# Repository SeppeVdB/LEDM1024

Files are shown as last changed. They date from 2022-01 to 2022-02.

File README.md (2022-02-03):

# LEDM1024

The LEDM1024 is a 32x32 LED screen made from scratch using an Atmega328p as the processor.

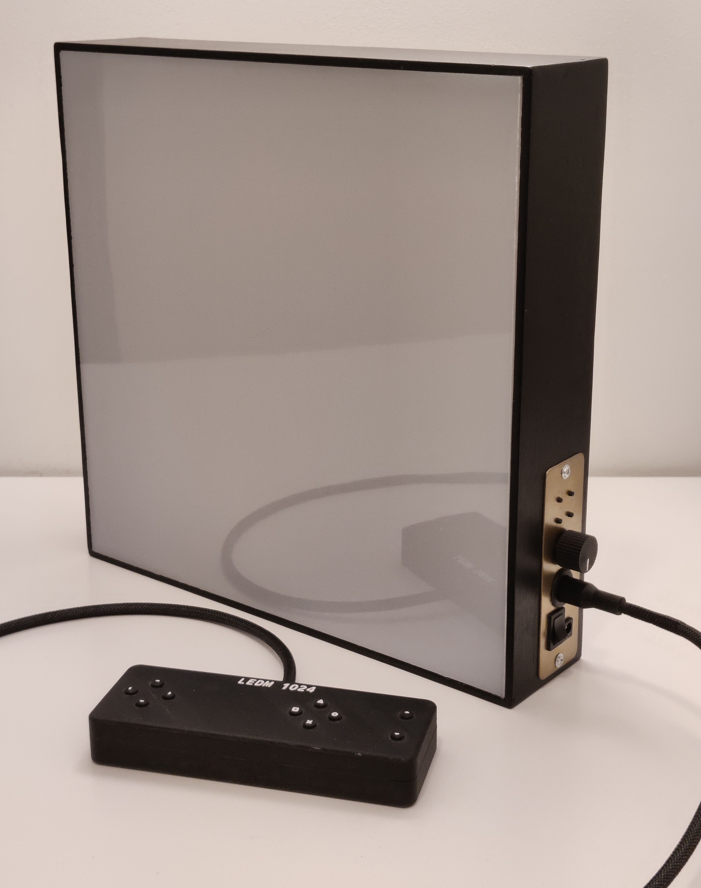
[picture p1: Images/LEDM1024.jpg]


## Applications

The available applications are John Conway's Game of Life, Snake and Pong.

John Conway's Game of Life has a random initial state and evolves until the state becomes stationary or starts oscillating between two states. After this, the app refreshes and a new random initial state is generated. Using the knob on the side panel, the frame rate can be adjusted.

To play Snake, the external controller is needed. The highscore is displayed on the menu screen and updates automatically when this score is exceeded. Normal Snake rules apply, so you lose when you hit the wall or the tail. Each food piece you consume, increases the score by 1. If the frame rate is high enough, the score is increased by 5.

To play Pong, the external controller and two players are needed. One player uses the leftmost up and down buttons and the second player uses the rightmost up and down buttons on the controller. Again, the knob on the side panel can be used to change the frame rate.

## Design

The casing is built around plywood sheet where all the LED's are mounted into. This sheet has a grid of 32x32 holes drilled and all the LED's are gluid in place. The LED leads are soldered to rails of copper wire to connect them in a grid like pattern. In the image below, the LED's are glued in place and the they are connected in rows using relatively thick copper wire to handle the current.

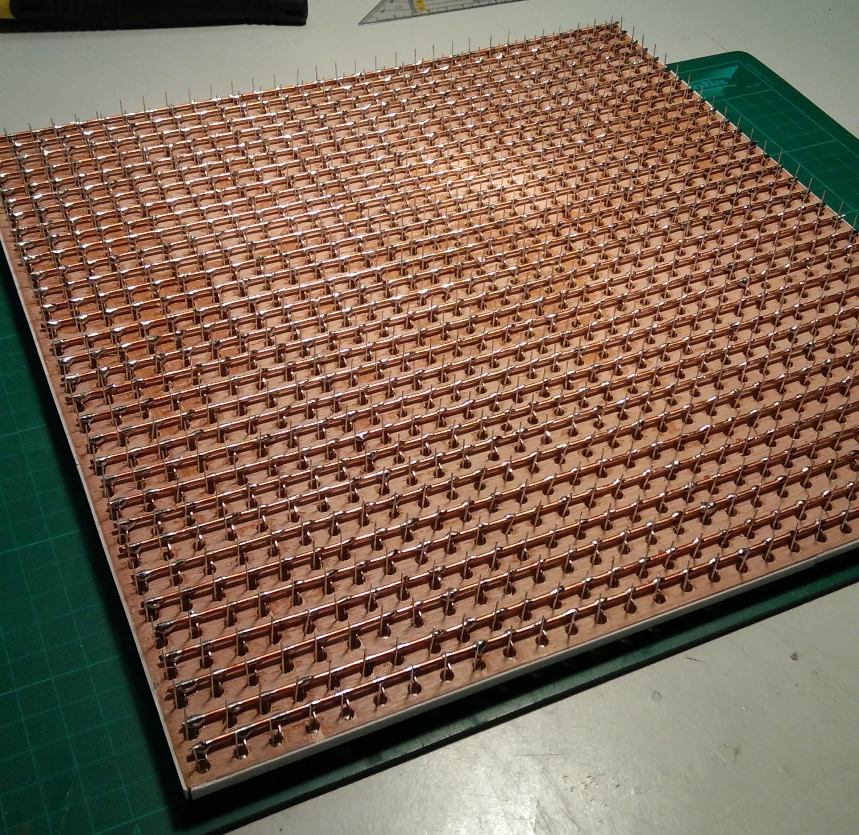
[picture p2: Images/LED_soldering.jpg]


The columns are soldered together using thinner wire and raised above the row connections. Lastly, the rows are connected in pairs to create the 16x64 structure instead of 32x32.

All the circuit boards containing the Atmega328p and shift registers, are mounted on the solder side of this sheet, raised using standoffs (insulated with heat shrink to prevent short circuits of the underlying wires). These circuit boards all receive a power line from the processor board and the signal lines are chained through the shift registers as shown below.

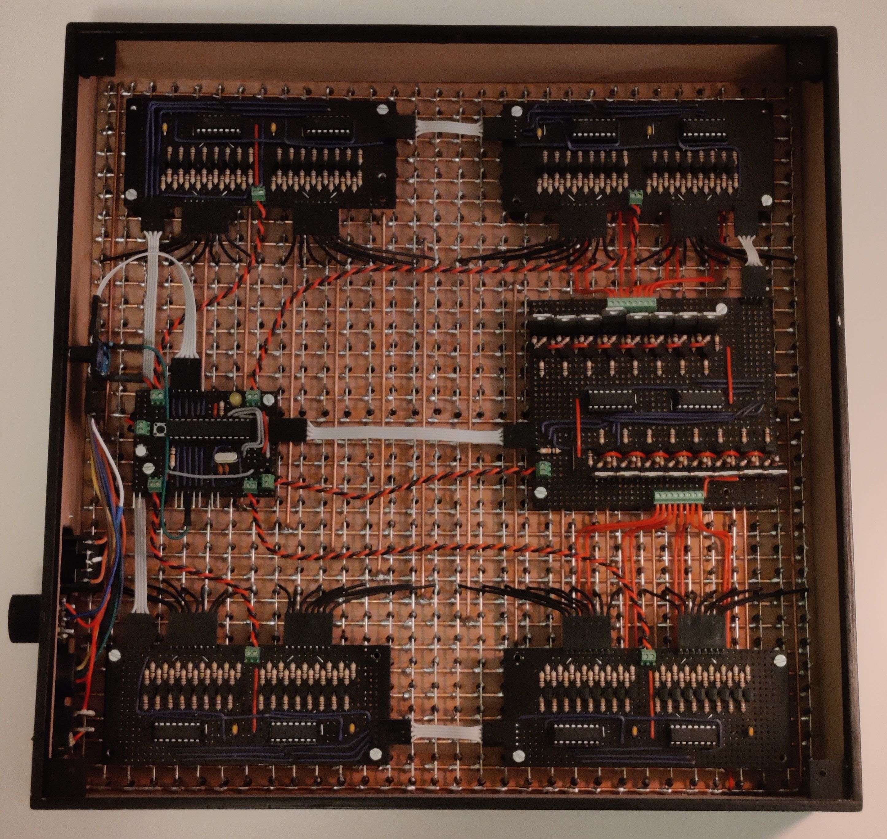
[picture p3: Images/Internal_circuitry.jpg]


The side panels are glued onto the central sheet. The right panel has a hole for the control panel which is made from a sheet of brass. Some 3d printed corner pieces allow for a clear acrylic sheet to be used as back plate. A clear acrylic sheet was chosen such that the internal circuitry is still visible.

To create a grid like pattern on the screen, a grid was 3d printed and inserted between the LED's.

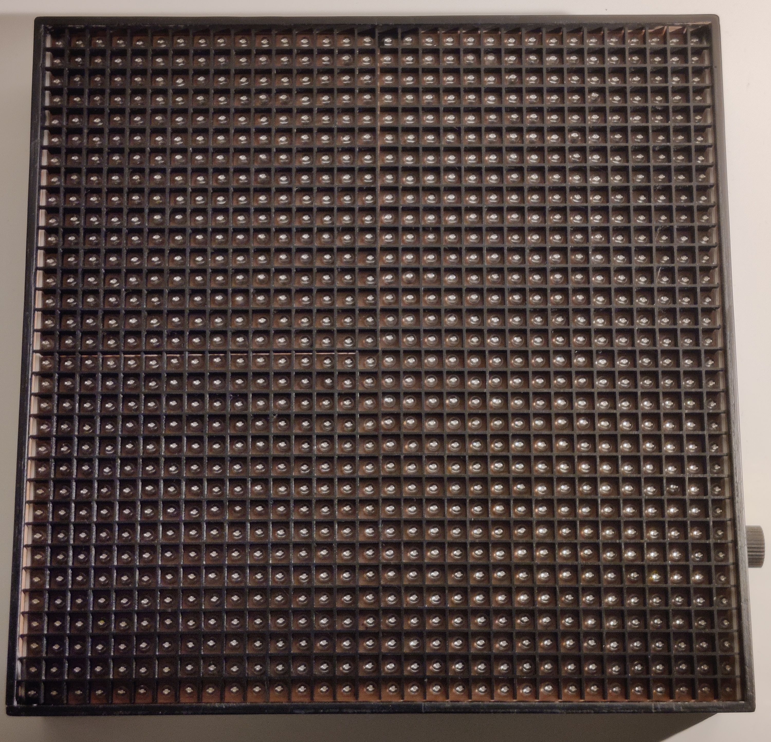
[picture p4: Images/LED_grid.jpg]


A diffusive acrylic plate is used as the front plate to create a pixel look.

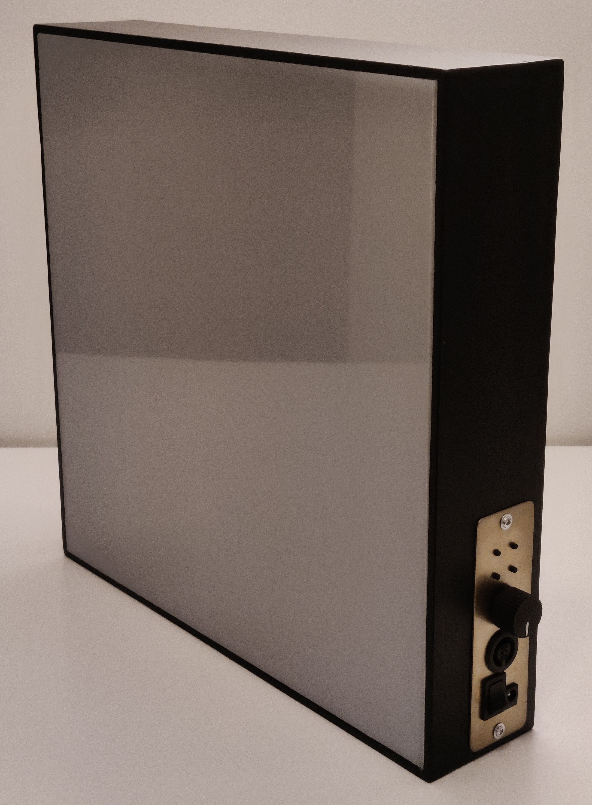
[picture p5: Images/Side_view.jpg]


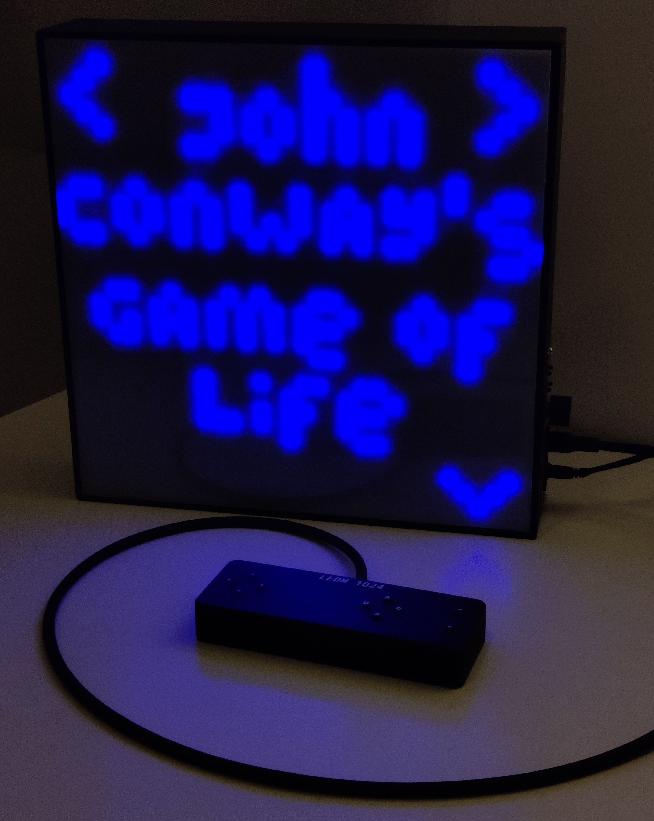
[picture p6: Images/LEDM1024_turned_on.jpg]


I'm sorry for the picture quality, but it is very difficult to capture the screen on camera. In reality the pixels are perfectly square.

## Electronics

### Processor

The processor is an Atmega328p (Arduino Uno chip). To control the 1024 LED's, 10 74HC595 shift registers are used together with multiplexing. Using these shift registers, the Atmega processor can control 80 separate pins using only four pins on the processor itself (clock, data, latch, and enable). The 32x32 LED grid is internally connected as if it where a 16x64 LED grid, resulting in 80 pins needed for multiplexing.

When multiplexing, each row of LED's is turned on separately. This is done at a frequency of about 8kHz to eliminate flickering. Because each row is only turned on 1/16 of the time, the perceived brightness of the LED's is also 1/16 of the normal brightness. This is the reason why the LED's are connected in a 16x64 grid, because a 32x32 grid would result in a brightness level of 1/32, which would be too low. Changing the layout to a 8x128 grid would increase the brightness to 1/8, which is better than 1/16, but this would increase the total amount of current that runs through one row. The operating current of each LED is 20mA, having 64 LED's in one row results in a total current per row of 1.28A. Compared to 2.56A in a 8x128 grid layout, a 16x64 layout was chosen as trade-off between brightness and total current.

### Controller

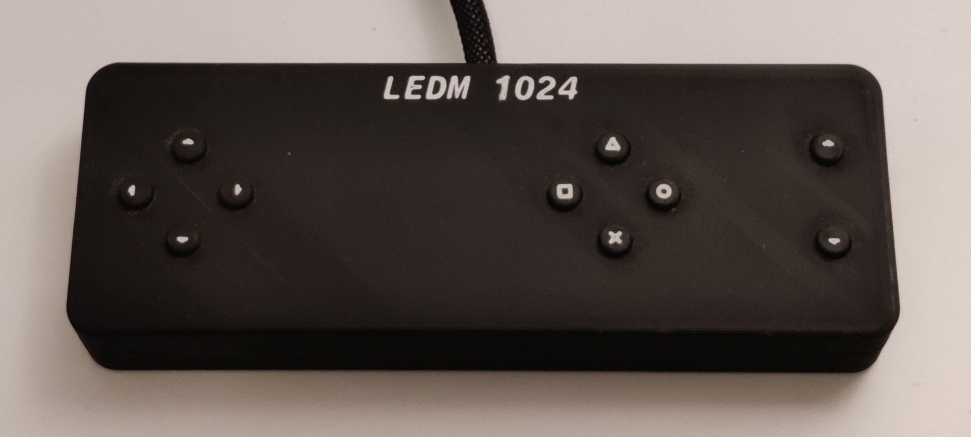
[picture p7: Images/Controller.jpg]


To play Snake and Pong, an external controller is needed to allow for more functionality. The external controller has 10 buttons and the side panel has four plus a rotating knob. Connecting these buttons in the conventional way, 15 pins would have to be used. The cable connecting the external controller would also have to house 12 separate cables (10 for the buttons, one ground, and one signal line to detect if the controller is plugged in). Because this kind of cable is not readily available, button multiplexing was used. Button multiplexing differs from LED multiplexing in that specific valued resistors are used to create an analog voltage signal depending on which buttons are pressed. The image below shows a diagram for multiplexing four buttons.

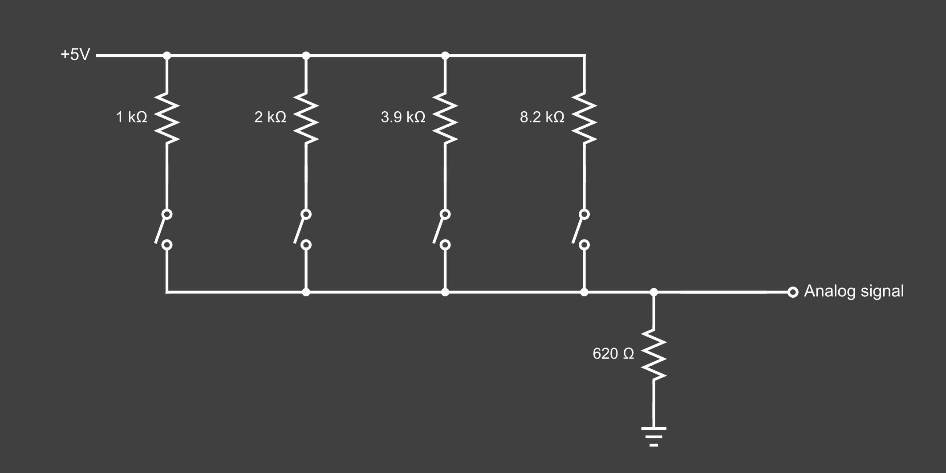
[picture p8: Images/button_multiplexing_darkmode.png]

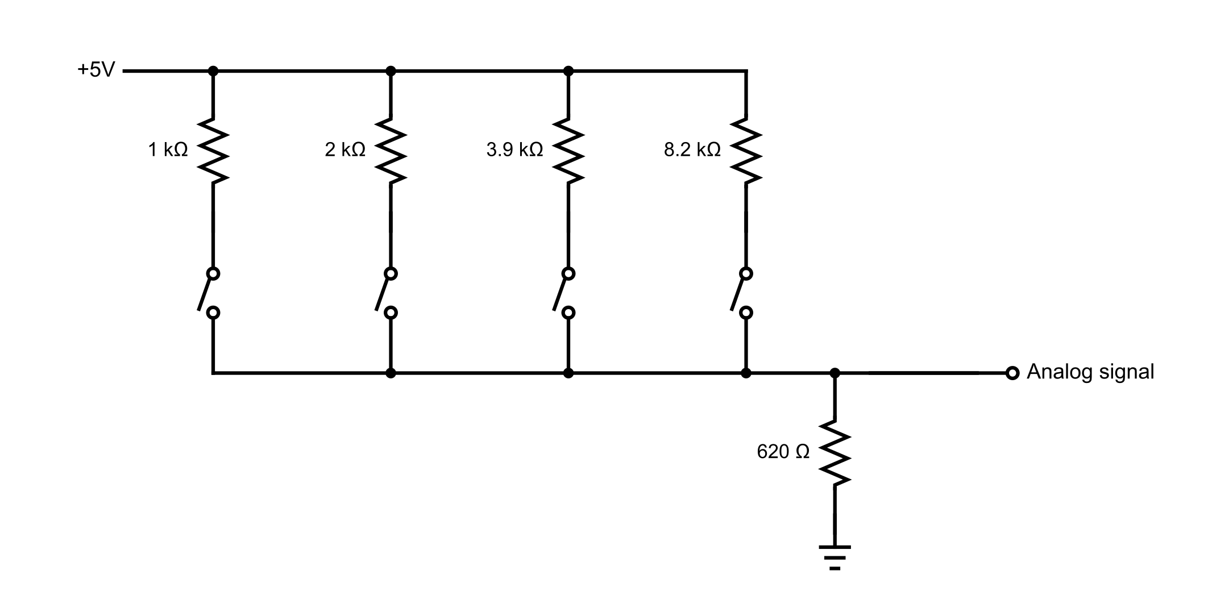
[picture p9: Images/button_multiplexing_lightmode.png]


After a lot of trial and error, these resistor values were chosen to maximise the voltage difference between different button pressed configurations. All the possible values are stored in a look up table. The values are ordered in ascending order, which has to convenient result that the binary represenation of the value position in the list corresponds to which buttons are pressed.

| Analog signal (0 - 255) | S1 | S2 | S3 | S4 |
|:---:|:--:|:--:|:--:|:--:|
| 0 |  0 |  0 |  0 |  0 |
| 17 |  0 |  0 |  0 |  1 |
| 34 |  0 |  0 |  1 |  0 |
| 48 |  0 |  0 |  1 |  1 |
| 60 |  0 |  1 |  0 |  0 |
| 70 |  0 |  1 |  0 |  1 |
| 81 |  0 |  1 |  1 |  0 |
| 89 |  0 |  1 |  1 |  1 |
| 97 |  1 |  0 |  0 |  0 |
| 104 |  1 |  0 |  0 |  1 |
| 111 |  1 |  0 |  1 |  0 |
| 117 |  1 |  0 |  1 |  1 |
| 122 |  1 |  1 |  0 |  0 |
| 127 |  1 |  1 |  0 |  1 |
| 132 |  1 |  1 |  1 |  0 |
| 137 |  1 |  1 |  1 |  1 |

Using this button multiplexing, only six signal cables are needed to connect the external controller: three for all the buttons, one ground, one +5V, and one signal line. The signal line is connected to ground inside the controller such that the processor knows when the external controller is plugged in.

## Image generator

Instead of manually editing an array of 128 bytes to create images, a python program was written to make life easier. The program uses Tkinter to create a simple UI. The program displays a grid of 32x32 cells which can be turned on/off individually by clicking on them. Other buttons allow the content of the display to be moved around, cleared, and exported into an array of 64 doubles which can be copied into the images.h file of the Arduino code.

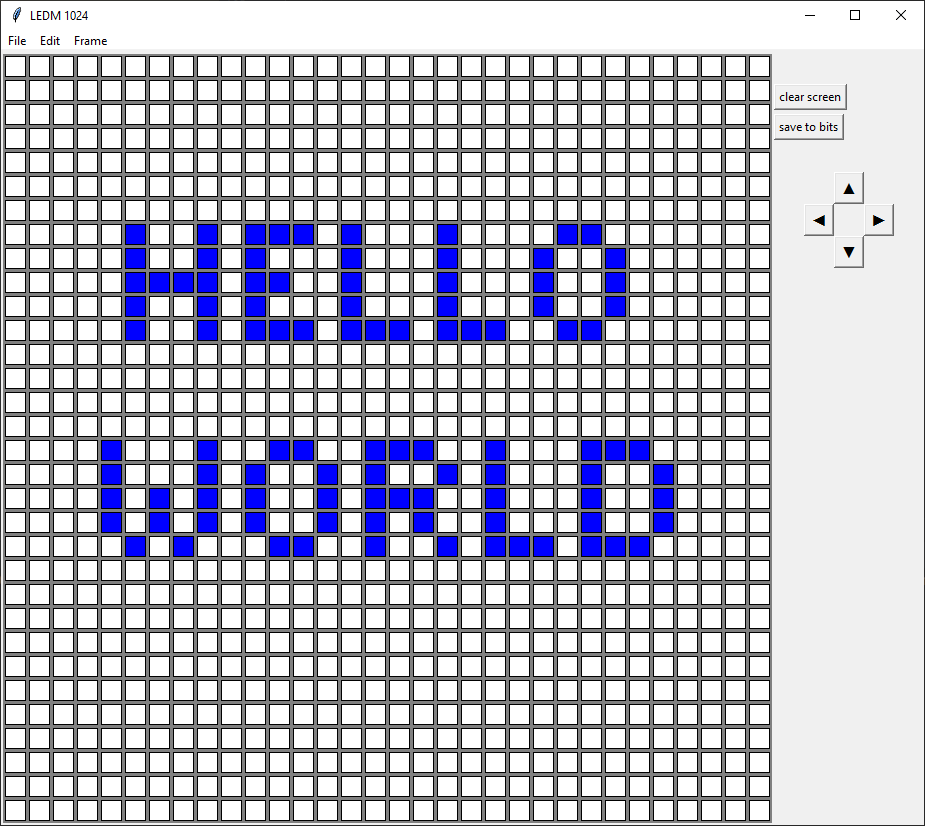
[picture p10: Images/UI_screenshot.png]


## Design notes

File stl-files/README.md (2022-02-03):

# STL files

## Notes

- The symbols on the buttons are printed by changing the filament color on the last layer.
- The button sleeves make sure the buttons stay in place. They are printed separately to allow for redesigning them depending on the distance between the circuit board and controller case.
- The connecter is designed to be fitted with standard male / female circuit board headers.

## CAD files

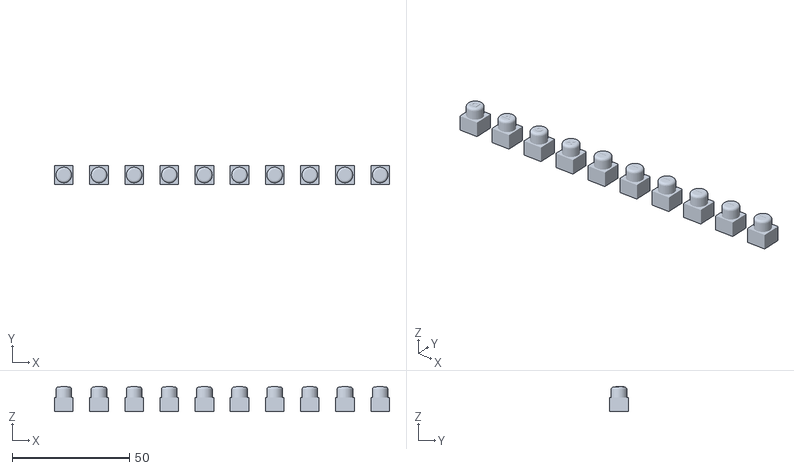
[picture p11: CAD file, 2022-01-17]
stl-files/controller_buttons_with_symbols.stl
143.0 x 8.00 x 10.7

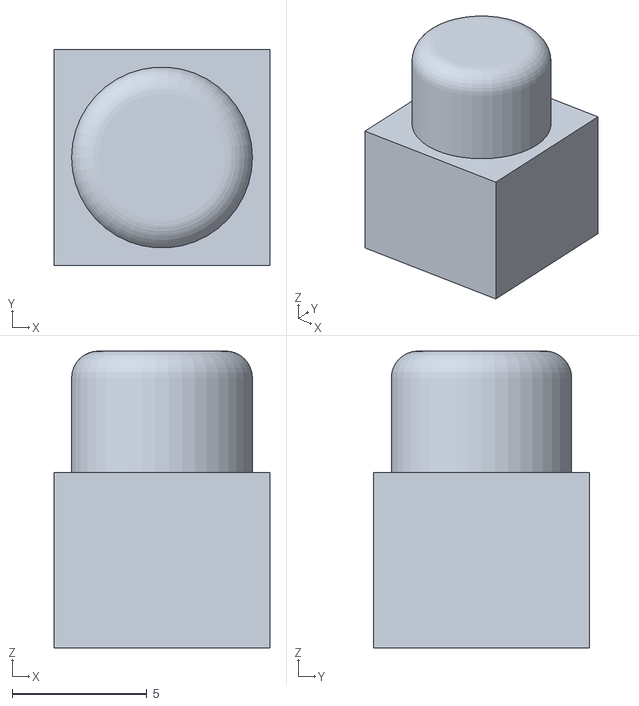
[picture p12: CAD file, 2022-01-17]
stl-files/controller_button_blank.stl
8.00 x 8.00 x 11.0

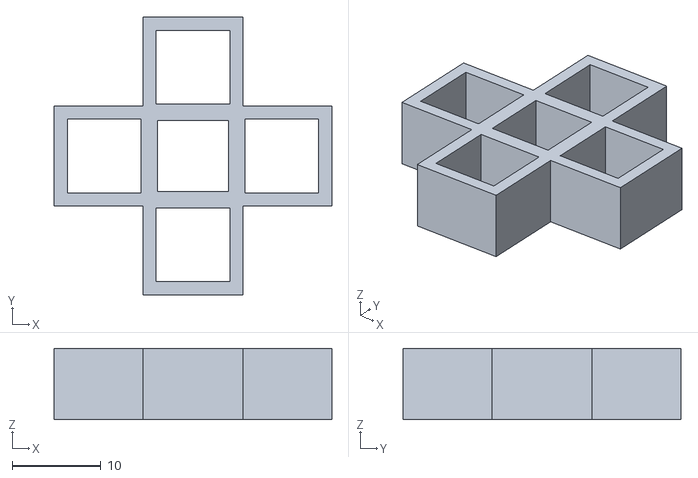
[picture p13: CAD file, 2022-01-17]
stl-files/controller_button_sleeve_4x.stl
31.3 x 31.3 x 8.00

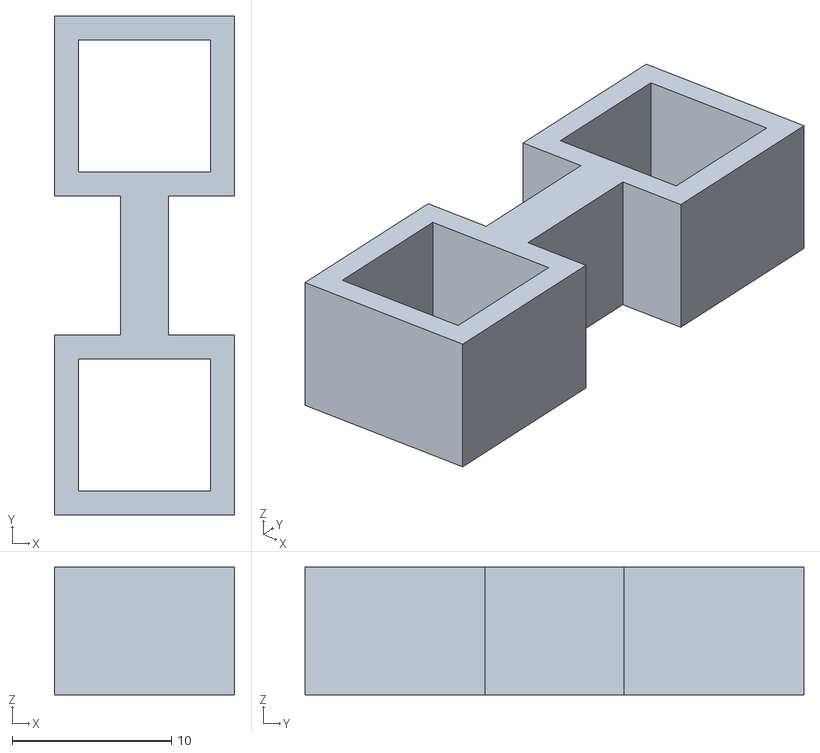
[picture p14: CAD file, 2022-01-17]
stl-files/controller_button_sleeve_2x.stl
11.3 x 31.3 x 8.00

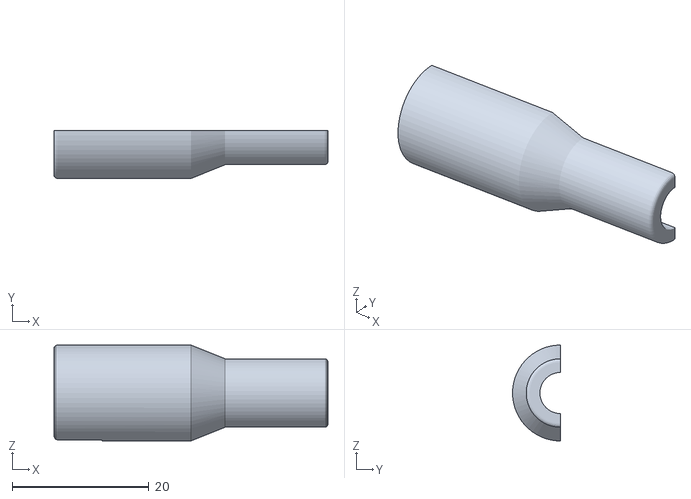
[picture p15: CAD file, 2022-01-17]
stl-files/6-pin_connector_male.stl
40.0 x 7.00 x 14.0

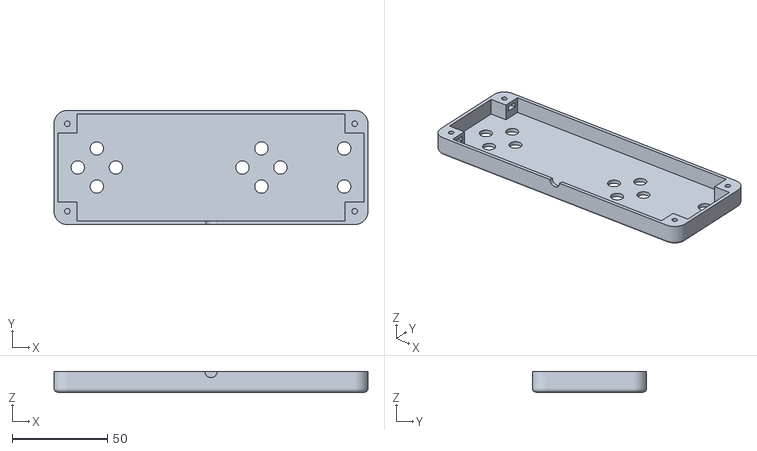
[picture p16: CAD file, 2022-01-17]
stl-files/controller_top_half.stl
165.0 x 60.0 x 11.2

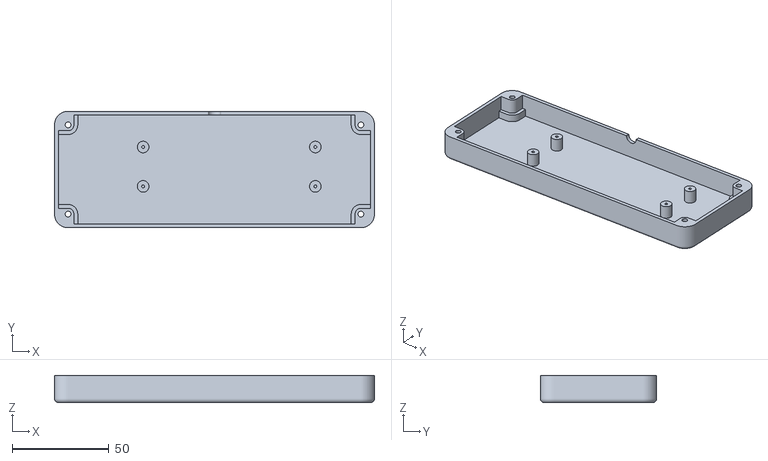
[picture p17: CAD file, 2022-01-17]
stl-files/controller_bottom_half.stl
165.0 x 60.0 x 14.0

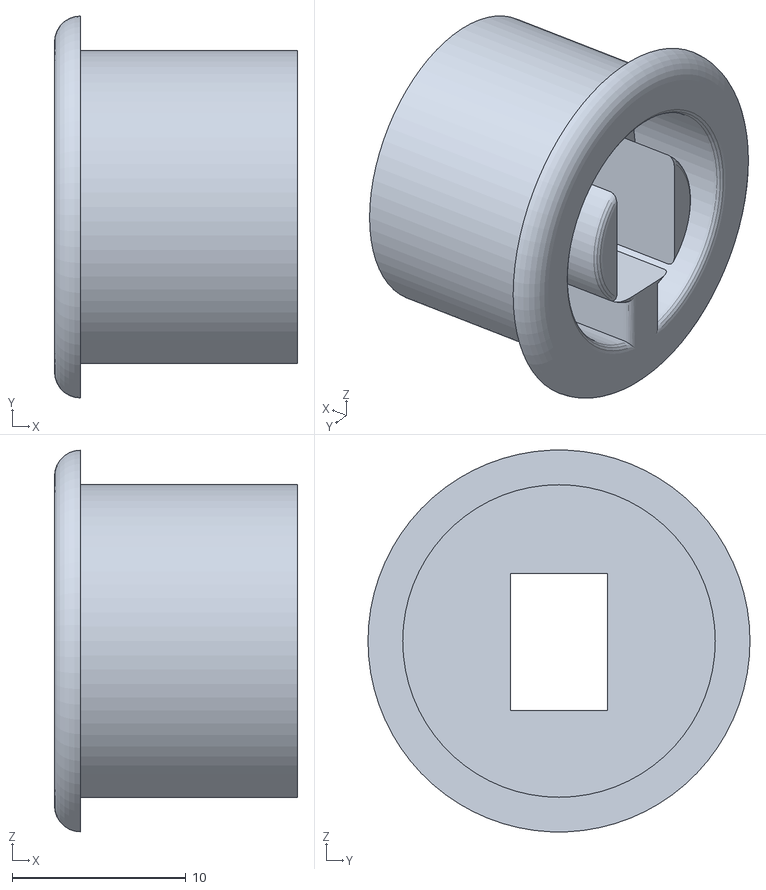
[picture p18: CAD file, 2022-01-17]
stl-files/6-pin_connector_female.stl
14.0 x 22.0 x 22.0

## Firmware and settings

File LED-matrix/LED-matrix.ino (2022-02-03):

/*
 * Code for LEDM 1024 by Seppe Van den Bergh 2022
 * 
 * This 32x32 LED screen is able to play John Conway's Game of Life, Snake, and Pong.
 * The external controller is needed to play Snake and Pong.
 * The turning knob on the side of the screen is used to adjust the frame rate during
 * the different applications. Therefore you can increase or decrease the difficulty
 * in Snake and Pong.
 * 
 * Enjoy!
 * 
 */

#include <SPI.h>
#include <EEPROM.h>
#include "images.h"

#define latch_pin 8
#define blank_pin 7
#define data_pin 11
#define clock_pin 13

#define buttons_1_pin A1
#define buttons_2_pin A2
#define buttons_3_pin A3
#define pot_pin A4
#define buttons_panel_pin A5
#define controller_check_pin 2


byte cathode[128];
byte anode[8];

byte button_values_4[15] = {8,  25,  41,  54,  65,  75,  85,  93,  100, 107, 114, 119, 124, 129, 134};
byte button_values_2[3] = {48, 112, 142};
uint16_t buttons_pressed = 0; // | control panel (4) | controller check (1) | left buttons (4) | middle buttons (4) | right buttons (2) | 0 |
char button_symbols[14] = {'R', 'L', 'X', 'O', 'L', 'D', 'R', 'U', 'S', 'X', 'O', 'T', 'u', 'd'};
byte pot_value;

//          controller               side panel
//  ╱¯¯¯¯¯¯¯¯¯¯¯¯¯¯¯¯¯¯¯¯¯¯¯╲     │¯¯¯¯¯¯¯¯¯¯│
// │    U         T       u  │    │  X    O  │
// │  L   R     S   O        │    │          │
// │    D         X       d  │    │  L    R  │
//  ╲_______________________╱     │__________│


// game of life variables
byte cathode_next[128];
byte cathode_past[128];
byte num_neigh = 0;
int num_empty = 0;

// snake game variables
byte food[2];
byte dir;
byte body[132];
byte head[2];
int snake_length = 0;
byte food_onoff = 1;
int score = 0;
int high_score = 0;

// pong game variables
byte paddles[2] = {17, 17};
float ball[2] = {15.0, 19.0};   // [0-31, 8-30]
float ball_prev[2] = {15.0, 19.0};
byte ball_byte[2] = {15, 19};
float angle = 0.0;
byte forward = 0;
byte upward = 0;
byte b = 14;
byte scores[2] = {0, 0};
byte start_dir = 1;

int shift_out;
byte anodelevel = 0;

byte rand_byte;

int i, j, k;  // for behind the scenes stuff
int m, n, o; // for applications
boolean play = true;
boolean game_over = false;
boolean menu = true;

byte screen_num = 0;
const int* menu_screens[3];
void setup_menu_screens(){
  menu_screens[0] = game_of_life_ss;
  menu_screens[1] = snake_ss;
  menu_screens[2] = pong_ss;
}
void (*applications[3])() {
  game_of_life,
  snake,
  pong
};

//////////////////////////////////////│¯¯¯¯¯¯¯│//////////////////////////////////////
//////////////////////////////////////│ Setup │//////////////////////////////////////
//////////////////////////////////////│_______│//////////////////////////////////////

void setup(){

  SPI.setBitOrder(LSBFIRST);
  SPI.setDataMode(SPI_MODE0);
  SPI.setClockDivider(SPI_CLOCK_DIV2);

  noInterrupts();

  TCCR1A = B00000000;
  TCCR1B = B00001011;     //bit 3 to activate interrupts, bit 0 and 1 to divide clock by 64: 16MHz/64=250kHz
  TIMSK1 = B00000010;     //bit 1 to call interrupt on OCR1A match
  OCR1A = 30;     //to calculate multiplex frequency: f = 250kHz/(OCR1A+1)
                  //with OCR1A=30: f = 250000/31 ≈ 8kHz

  for(i=7; i>-1; i--){
    bitSet(anode[i], i);
  }
  for(i=0; i<128; i++){
    cathode[i] = 0;
  }

  EEPROM.get(0, high_score);
  if(high_score < 2){
    high_score = 23;
    EEPROM.put(0, high_score);
  }
  
  pinMode(latch_pin, OUTPUT);     //Latch
  pinMode(data_pin, OUTPUT);      //MOSI DATA
  pinMode(clock_pin, OUTPUT);     //SPI Clock
  pinMode(blank_pin, OUTPUT);     //Output Enable  important to do this last, so LEDs do not flash on boot up
  SPI.begin();      //start up the SPI library
  interrupts();     //start multiplexing

  randomSeed(analogRead(0));

  setup_menu_screens();
}

//////////////////////////////////////│¯¯¯¯¯¯│//////////////////////////////////////
//////////////////////////////////////│ Loop │//////////////////////////////////////
//////////////////////////////////////│______│//////////////////////////////////////

void loop(){
  while(menu){
    buttonRead();
    displayFile(menu_screens[screen_num]);

    if(screen_num == 1){
      EEPROM.get(0, high_score);
      displayNumber(high_score, 24, 3);
      delay(50);
    }
    
    switch(whichButton()){
      case 'L':
        if(screen_num == 0) screen_num = 2;
        else screen_num --;
        scroll(menu_screens[screen_num], 'L', 20);
        break;
      case 'R':
        if(screen_num == 2) screen_num = 0;
        else screen_num ++;
        scroll(menu_screens[screen_num], 'R', 20);
        break;
      case 'D':
      case 'd':
      case 'X':
        if(screen_num > 0 and !controllerCheck()){
          showError();
          delay(500);
          break;
        }
        play = true;
        game_over = false;
        applications[screen_num]();
        break;
    }
  }
}

//////////////////////////////////////│¯¯¯¯¯¯¯¯¯¯¯│//////////////////////////////////////
//////////////////////////////////////│ Functions │//////////////////////////////////////
//////////////////////////////////////│___________│//////////////////////////////////////

void LED(byte row, byte column, boolean state){
  row = constrain(row, 0, 31);
  column = constrain(column, 0, 31);
  byte whichbyte = constrain((row*32+column)/8, 0, 127);
  byte whichbit = column%8;

  bitWrite(cathode[whichbyte], 7-whichbit, state);
}

void displayFile(uint16_t image[64]){
  for(i=0; i<32; i++){
    cathode[4*i] = highByte(image[i*2]);
    cathode[4*i+1] = lowByte(image[i*2]);
    cathode[4*i+2] = highByte(image[i*2+1]);
    cathode[4*i+3] = lowByte(image[i*2+1]);
  }
}

void scroll(uint16_t image[64], char side, int delay_time){
  if(side == 'L' || side == 'W'){
    for(i=0; i<32; i++){
      for(j=0; j<32; j++){
        cathode[j*4+3] = cathode[j*4+3] >> 1;
        bitWrite(cathode[j*4+3], 7, bitRead(cathode[j*4+2], 0));
        cathode[j*4+2] = cathode[j*4+2] >> 1;
        bitWrite(cathode[j*4+2], 7, bitRead(cathode[j*4+1], 0));
        cathode[j*4+1] = cathode[j*4+1] >> 1;
        bitWrite(cathode[j*4+1], 7, bitRead(cathode[j*4], 0));
        cathode[j*4] = cathode[j*4] >> 1;
        bitWrite(cathode[j*4], 7, bitRead(image[j*2+1-i/16], i-16*(i/16)));
      }
      delay(delay_time);
    }
  }else if(side == 'R' || side == 'E'){
    for(i=0; i<32; i++){
      for(j=0; j<32; j++){
        cathode[j*4] = cathode[j*4] << 1;
        bitWrite(cathode[j*4], 0, bitRead(cathode[j*4+1], 7));
        cathode[j*4+1] = cathode[j*4+1] << 1;
        bitWrite(cathode[j*4+1], 0, bitRead(cathode[j*4+2], 7));
        cathode[j*4+2] = cathode[j*4+2] << 1;
        bitWrite(cathode[j*4+2], 0, bitRead(cathode[j*4+3], 7));
        cathode[j*4+3] = cathode[j*4+3] << 1;
        bitWrite(cathode[j*4+3], 0, bitRead(image[j*2+i/16], 15-i+16*(i/16)));
      }
      delay(delay_time);
    }
  }else if(side == 'U' || side == 'N'){
    for(i=31; i>-1; i--){
      for(j=31; j>0; j--){
        cathode[j*4] = cathode[j*4-4];
        cathode[j*4+1] = cathode[j*4-3];
        cathode[j*4+2] = cathode[j*4-2];
        cathode[j*4+3] = cathode[j*4-1];
      }
      cathode[0] = highByte(image[i*2]);
      cathode[1] = lowByte(image[i*2]);
      cathode[2] = highByte(image[i*2+1]);
      cathode[3] = lowByte(image[i*2+1]);
      delay(delay_time);
    }
  }else if(side == 'D' || side == 'S'){
    for(i=0; i<32; i++){
      for(j=0; j<31; j++){
        cathode[j*4] = cathode[j*4+4];
        cathode[j*4+1] = cathode[j*4+5];
        cathode[j*4+2] = cathode[j*4+6];
        cathode[j*4+3] = cathode[j*4+7];
      }
      cathode[124] = highByte(image[i*2]);
      cathode[125] = lowByte(image[i*2]);
      cathode[126] = highByte(image[i*2+1]);
      cathode[127] = lowByte(image[i*2+1]);
      delay(delay_time);
    }
  }
}

boolean isEqual(byte array_1[128], byte array_2[128]){
  for(i=0; i<128; i++) if(array_1[i] != array_2[i]) return false;
  return true;
}

void clearScreen(){
  memset(cathode, 0, sizeof(cathode));
}

uint16_t buttonRead(){
  byte buttons_panel = map(analogRead(buttons_panel_pin), 0, 1023, 0, 255);
  byte controller = digitalRead(controller_check_pin);
  pot_value = map(analogRead(pot_pin), 0, 1023, 0, 255);

  byte index_1 = 7;
  for(i=0; i<3; i++){
    if(buttons_panel < button_values_4[index_1]){
      bitClear(buttons_pressed, 15-i);
      index_1 -= 1 << (2-i);
    } else{
      bitSet(buttons_pressed, 15-i);
      index_1 += 1 << (2-i);
    }
  }
  bitWrite(buttons_pressed, 12, !(buttons_panel < button_values_4[index_1]));

  if(controller == LOW){
    bitSet(buttons_pressed, 1);

    byte buttons_1 = map(analogRead(buttons_1_pin), 0, 1023, 0, 255);
    byte buttons_2 = map(analogRead(buttons_2_pin), 0, 1023, 0, 255);
    byte buttons_3 = map(analogRead(buttons_3_pin), 0, 1023, 0, 255);

    index_1 = 7;
    byte index_2 = 7;
    for(i=0; i<3; i++){
      if(buttons_1 < button_values_4[index_1]){
        bitClear(buttons_pressed, 11-i);
        index_1 -= 1 << (2-i);
      } else{
        bitSet(buttons_pressed, 11-i);
        index_1 += 1 << (2-i);
      }
      if(buttons_2 < button_values_4[index_2]){
        bitClear(buttons_pressed, 7-i);
        index_2 -= 1 << (2-i);
      } else{
        bitSet(buttons_pressed, 7-i);
        index_2 += 1 << (2-i);
      }
    }
    bitWrite(buttons_pressed, 8, !(buttons_1 < button_values_4[index_1]));
    bitWrite(buttons_pressed, 4, !(buttons_2 < button_values_4[index_2]));
    if(buttons_3 < button_values_2[1]){
      bitClear(buttons_pressed, 3);
      bitWrite(buttons_pressed, 2, !(buttons_3 < button_values_2[0]));
    } else{
      bitSet(buttons_pressed, 3);
      bitWrite(buttons_pressed, 2, !(buttons_3 < button_values_2[2]));
    }
  } else buttons_pressed &= 0b1111000000000000;
}

boolean controllerCheck(){
  return bitRead(buttons_pressed, 1);
}

boolean buttonCheck(char button){
  switch(button){
    case 'd':   // down controller (right side)
      return bitRead(buttons_pressed, 2);
    case 'u':   // up controller (right side)
      return bitRead(buttons_pressed, 3);
    case 'T':   // triangle controller
      return bitRead(buttons_pressed, 4);
    case 'O':   // circle controller or panel
      return bitRead(buttons_pressed, 5) or bitRead(buttons_pressed, 12);
    case 'X':   // cross controller or panel
      return bitRead(buttons_pressed, 6) or bitRead(buttons_pressed, 13);
    case 'S':   // square controller
      return bitRead(buttons_pressed, 7);
    case 'U':   // up controller (left side)
      return bitRead(buttons_pressed, 8);
    case 'R':   // right controller or panel
      return bitRead(buttons_pressed, 9) or bitRead(buttons_pressed, 15);
    case 'D':   // down controller (left side)
      return bitRead(buttons_pressed, 10);
    case 'L':   // left controller or panel
      return bitRead(buttons_pressed, 11) or bitRead(buttons_pressed, 14);
  }
}

char whichButton(){
  for(i=0; i<14; i++){
    if(bitRead(buttons_pressed << i, 15)) return button_symbols[i];
  }
  return 'E';
}

void displayDigit(byte num, byte row, byte column){
  row = constrain(row, 0, 27);
  column = constrain(column, 0, 29);
  byte whichbyte_1 = (row*32+column)/8;
  byte whichbyte_2 = (row*32+column+1)/8;
  byte whichbyte_3 = (row*32+column+2)/8;
  byte whichbit_1 = 7 - column%8;
  byte whichbit_2 = 7 - (column+1)%8;
  byte whichbit_3 = 7 - (column+2)%8;
  
  if(num == 0){
    bitSet(cathode[whichbyte_2], whichbit_2);
    bitSet(cathode[whichbyte_2+16], whichbit_2);
    for(i=0; i<5; i++){
      bitSet(cathode[whichbyte_1+4*i], whichbit_1);
      bitSet(cathode[whichbyte_3+4*i], whichbit_3);
    }
  }else if(num == 1){
    for(i=0; i<5; i++){
      bitSet(cathode[whichbyte_1+4*i], whichbit_1);
    }
  }else if(num == 2){
    for(i=0; i<3; i++){
      bitSet(cathode[whichbyte_1+8*i], whichbit_1);
      bitSet(cathode[whichbyte_2+8*i], whichbit_2);
      bitSet(cathode[whichbyte_3+8*i], whichbit_3);
    }
    bitSet(cathode[whichbyte_1+12], whichbit_1);
    bitSet(cathode[whichbyte_3+4], whichbit_3);
  }else if(num == 3){
    for(i=0; i<3; i++){
      bitSet(cathode[whichbyte_1+8*i], whichbit_1);
      bitSet(cathode[whichbyte_2+8*i], whichbit_2);
      bitSet(cathode[whichbyte_3+8*i], whichbit_3);
    }
    bitSet(cathode[whichbyte_3+4], whichbit_3);
    bitSet(cathode[whichbyte_3+12], whichbit_3);
  }else if(num == 4){
    bitSet(cathode[whichbyte_2+8], whichbit_2);
    for(i=0; i<5; i++){
      bitSet(cathode[whichbyte_3+4*i], whichbit_3);
      if(i<3) bitSet(cathode[whichbyte_1+4*i], whichbit_1);
    }
  }else if(num == 5){
    for(i=0; i<3; i++){
      bitSet(cathode[whichbyte_1+8*i], whichbit_1);
      bitSet(cathode[whichbyte_2+8*i], whichbit_2);
      bitSet(cathode[whichbyte_3+8*i], whichbit_3);
    }
    bitSet(cathode[whichbyte_1+4], whichbit_1);
    bitSet(cathode[whichbyte_3+12], whichbit_3);
  }else if(num == 6){
    for(i=0; i<3; i++){
      bitSet(cathode[whichbyte_1+8*i], whichbit_1);
      bitSet(cathode[whichbyte_2+8*i], whichbit_2);
      bitSet(cathode[whichbyte_3+8*i], whichbit_3);
    }
    bitSet(cathode[whichbyte_1+4], whichbit_1);
    bitSet(cathode[whichbyte_3+12], whichbit_3);
    bitSet(cathode[whichbyte_1+12], whichbit_1);
  }else if(num == 7){
    bitSet(cathode[whichbyte_1], whichbit_1);
    bitSet(cathode[whichbyte_2], whichbit_2);
    bitSet(cathode[whichbyte_3], whichbit_3);
    bitSet(cathode[whichbyte_3+4], whichbit_3);
    bitSet(cathode[whichbyte_2+8], whichbit_2);
    bitSet(cathode[whichbyte_1+12], whichbit_1);
    bitSet(cathode[whichbyte_1+16], whichbit_1);
  }else if(num == 8){
    for(i=0; i<5; i++){
      bitSet(cathode[whichbyte_1+4*i], whichbit_1);
      bitSet(cathode[whichbyte_3+4*i], whichbit_3);
      if(i%2 == 0 || i == 0) bitSet(cathode[whichbyte_2+4*i], whichbit_2);
    }
  }else if(num == 9){
    for(i=0; i<3; i++){
      bitSet(cathode[whichbyte_1+8*i], whichbit_1);
      bitSet(cathode[whichbyte_2+8*i], whichbit_2);
      bitSet(cathode[whichbyte_3+8*i], whichbit_3);
    }
    bitSet(cathode[whichbyte_1+4], whichbit_1);
    bitSet(cathode[whichbyte_3+4], whichbit_3);
    bitSet(cathode[whichbyte_3+12], whichbit_3);
  }else if(num==10){
    for(i=0; i<5; i++){
      bitClear(cathode[whichbyte_1+4*i], whichbit_1);
      bitClear(cathode[whichbyte_2+4*i], whichbit_2);
      bitClear(cathode[whichbyte_3+4*i], whichbit_3);
    }
  }
}

void displayNumber(int num, byte row, byte column){
  byte current_column = column;
  String num_str = String(num);
  for(j=0; j<num_str.length(); j++){
    displayDigit(num_str.charAt(j) - '0', row, current_column);
    if(num_str.charAt(j) == '1') current_column += 2;
    else current_column += 4;
  }
}

void countdown(byte row, byte column){
  for(m=15; m>=0; m--){
    displayDigit(10, row, column);
    displayDigit(m/4, row, column+(m/4==1));
    buttonRead();
      switch(whichButton()){
        case 'O':
          play = false;
          m = -1;
          break;
        case 'T':
          pauseScreen();
          break;
      }
    delay(250);
  }
  displayDigit(10, row, column);
}

void showError(){
  for(i=0; i<11; i++){
    for(j=0; j<11; j++){
      if((j>0 and j<10 and (i==1 or i==9)) or (i>0 and i<10 and (j==1 or j==9)) or ((i==j or i==10-j) and j>2 and j<8)) LED(i+21, j+21, 1);
      else LED(i+21, j+21, 0);
    }
  }
}

void pauseScreen(){
  memcpy(cathode_past, cathode, sizeof(cathode));
  for(i=33; i<92; i+=4){
    cathode[i] = 0;
    cathode[i+1] = 0;
    if(i>40 and i<83){
      cathode[i] = highByte(play_logo[(i-41)/4]);
      cathode[i+1] = lowByte(play_logo[(i-41)/4]);
    }
  }
  delay(500);
  buttonRead();
  while(whichButton() == 'E'){
    buttonRead();
  }
  memcpy(cathode, cathode_past, sizeof(cathode));
  delay(500);
}

//////////////////////////////////////│¯¯¯¯¯¯¯¯¯¯¯│//////////////////////////////////////
//////////////////////////////////////│ Interrupt │//////////////////////////////////////
//////////////////////////////////////│___________│//////////////////////////////////////

ISR(TIMER1_COMPA_vect){
    PORTD |= 1<<blank_pin;    //turn all the LEDs off

    SPCR |= _BV(DORD);    //set bitorder to LSBFIRST

    for(shift_out=anodelevel*4+64; shift_out<anodelevel*4+68; shift_out++){
        SPI.transfer(cathode[shift_out]);
    }

    SPCR &= ~(_BV(DORD));   //set bitorder to MSBFIRST

    for(shift_out=anodelevel*4+3; shift_out>=anodelevel*4; shift_out--){
        SPI.transfer(cathode[shift_out]);
    }

    if(anodelevel<8){
        SPI.transfer(0);
        SPI.transfer(anode[anodelevel]);
    }else{
        SPI.transfer(anode[anodelevel-8]);
        SPI.transfer(0);
    }

    PORTB |= 1<<0;      //Latch pin HIGH
    PORTB &= 0<<0;      //Latch pin LOW
    PORTD &= 0<<blank_pin;      //Blank pin LOW to turn on the LEDs with the new data

    anodelevel ++;
    if(anodelevel == 16) anodelevel = 0;
}

/////////////////////////////////////│¯¯¯¯¯¯¯¯¯¯¯¯¯¯│/////////////////////////////////////
/////////////////////////////////////│ Applications │/////////////////////////////////////
/////////////////////////////////////│______________│/////////////////////////////////////

void game_of_life(){
  while(play){
    for(i=0; i<128; i++){
      cathode[i] = lowByte(random(256));
    }
    memcpy(cathode_past, cathode, sizeof(cathode));
    game_over = false;
    while(play and !game_over){
      num_empty = 0;
      for(m=0; m<32; m++){
        for(n=0; n<32; n++){
          num_neigh = number_neighbours(m, n);
          if(bitRead(cathode[(m*32+n)/8], 7-n%8)){
            if(num_neigh == 2 || num_neigh == 3) bitSet(cathode_next[(m*32+n)/8], 7-n%8);
          }else{
            if(num_neigh == 3) bitSet(cathode_next[(m*32+n)/8], 7-n%8);
            num_empty ++;
          }
        }
      }
      if(num_empty == 1024 || isEqual(cathode, cathode_next) || isEqual(cathode_next, cathode_past)) break;
      memcpy(cathode_past, cathode, sizeof(cathode));
      memcpy(cathode, cathode_next, sizeof(cathode));
      memset(cathode_next, 0, sizeof(cathode_next));
  
      buttonRead();
      switch(whichButton()){
        case 'O':
          play = false;
          break;
        case 'S':
          game_over = true;
          break;
      }
      
      delay(pot_value/3);
    }
  }
}

byte number_neighbours(int row, int column){
  byte output = 0;
  if(column < 31) output += bitRead(cathode[((row)*32+(column+1))/8], 7-(column+1)%8);
  if(column > 0) output += bitRead(cathode[((row)*32+(column-1))/8], 7-(column-1)%8);
  if(row < 31) output += bitRead(cathode[((row+1)*32+(column))/8], 7-(column)%8);
  if(row < 31 && column < 31) output += bitRead(cathode[((row+1)*32+(column+1))/8], 7-(column+1)%8);
  if(row < 31 && column > 0) output += bitRead(cathode[((row+1)*32+(column-1))/8], 7-(column-1)%8);
  if(row > 0) output += bitRead(cathode[((row-1)*32+(column))/8], 7-(column)%8);
  if(row > 0 && column < 31) output += bitRead(cathode[((row-1)*32+(column+1))/8], 7-(column+1)%8);
  if(row > 0 && column > 0) output += bitRead(cathode[((row-1)*32+(column-1))/8], 7-(column-1)%8);
  return output;
}

void snake(){
  displayFile(snake_ps);
  delay(500);
  snake_length = 2;
  score = 0;
  head[0] = 10;    // starting row
  head[1] = 5;    // starting column
  body[0] = 10;   // set bits 0-3 to 1
  dir = 2;
  
  food[0] = random(8, 30);
  food[1] = random(2, 26);
  
  make_snake();
  LED(food[0], food[1], 1);
  displayDigit(0, 1, 1);

  countdown(1, 20);

  while(play and !game_over){
    buttonRead();
    
    for(m=0; m<4; m++){
      if(bitRead(buttons_pressed, 11-m) and m != dir+2 and dir != m+2){
        dir = m;
        break;
      }
    }

    snake_step();
    make_snake();
    if(head[0] == food[0] and head[1] == food[1]){
      snake_length ++;
      score += 1+4*(pot_value<5);
      food[0] = random(8, 30);
      food[1] = random(2, 26);
      LED(food[0], food[1], 1);
      food_onoff = 8;
      for(m=4; m<24; m++) if((m+1)%4 != 0) cathode[m] = 0;
      displayNumber(score, 1, 1);
    }

    food_onoff ++;
    LED(food[0], food[1], bitRead(food_onoff, 3));
    
    if(head[0] < 8 or head[0] > 29 or head[1] < 2 or head[1] > 25) game_over = true;
    buttonRead();
    switch(whichButton()){
      case 'O':
        play = false;
        break;
      case 'S':
        game_over = true;
        break;
      case 'T':
        pauseScreen();
        break;
    }
    if(!controllerCheck()){
      play = false;
      game_over = false;
    }
    delay(pot_value/2+20);
  }
  if(game_over){
    for(n=0; n<4; n++){
      for(m=4; m<24; m++) if((m+1)%4 != 0) cathode[m] = 0;
      delay(250);
      displayNumber(score, 1, 1);
      delay(250);
      buttonRead();
      if(buttonCheck('O')){
        play = false;
        break;
      }
    }
    EEPROM.get(0, high_score);
    if(score > high_score) EEPROM.put(0, score);
    game_over = false;
    if(play) snake();
  }
}

void make_snake(){
  byte current_dir;
  byte current_pos[2] = {head[0], head[1]};
  for(m=0; m<snake_length; m++){
    LED(current_pos[0], current_pos[1], 1);
    if(head[0] == current_pos[0] and head[1] == current_pos[1] and m>0) game_over = true;
    current_dir = bitRead(body[m/4], m%4*2) + bitRead(body[m/4], m%4*2+1)*2;
    if(current_dir == 0) current_pos[1] --;
    if(current_dir == 1) current_pos[0] ++;
    if(current_dir == 2) current_pos[1] ++;
    if(current_dir == 3) current_pos[0] --;
  }
  LED(current_pos[0], current_pos[1], 0);
}

void snake_step(){
  for(m=(snake_length-1)/4; m>-1; m--){
    if(m < 131){
      bitWrite(body[m+1], 0, bitRead(body[m], 6));
      bitWrite(body[m+1], 1, bitRead(body[m], 7));
    }
    body[m] = body[m] << 2;
  }
  bitWrite(body[0], 0, bitRead((dir+2)%4, 0));
  bitWrite(body[0], 1, bitRead((dir+2)%4, 1));
  if(dir == 0) head[1] --;
  if(dir == 1) head[0] ++;
  if(dir == 2) head[1] ++;
  if(dir == 3) head[0] --;
}
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
